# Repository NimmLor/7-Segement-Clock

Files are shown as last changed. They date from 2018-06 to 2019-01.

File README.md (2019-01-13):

# THIS REPO IS NO LONGER UPDATED, VISIT THE THINGIVERSE PROJECT FOR UPDATED FILES

This is a fully 3D printed clock that was designed in Fusion 360. The project is based on [Ivan Miranda's Big Digital Clock](https://ivanmiranda.com/diy-big-digital-clock) and was completely re-designed.

## If you have any questions or issues feel free contact me 

#### *Mini version* of the clock coming soon :)

## Changelog:

## Major Software Update: 24.09.2018
**Make sure to update all your libraries (3 dashes → manage palette → update)**
- **LOTS OF BUG FIXES**
  - Clock does no longer light up every 6 hours even when turned of
  - Fixed a bug when clock mode was selected at 00:00 - 00:59 that it would made it show e.g. 24:15
  - Fixed random reboots
  - Fixed that alarm wouldn't trigger at the correct time
  - Fixed a bug that occured when the API-key of *openweathermap* wasn't set
  - Fixed error spamming in debug console of Node-red
  - Fixed that timer would skip 1 second every minute
  - Fixed bugs that would result in a crash of the clock
  - and much more...
- Removed unnecessary buttons in the UI
- Added a **settings tab** to the UI, the *settings* section in the ui got moved over there
- Clock is now **more precise**
- Timer is now capable of displaying HH:MM and MM:SS format, depending on the remaining time
- **SOURCE CODE OVERHAUL**
  - Functions are now **modular**
  - Added tons of **comments**
  - Made the code **readable**
  - **New** functions
  - Clock/Timer works now more precise (the clock shouldn't be off time more than 2 secs)
  - Functions utilize much less global variables making the code easier to modify
  - Weather algorithm got fixed
  - Fade works more stable now and shouldn't cause a crash anymore
  - Time is now set in **HH:MM:SS** before it was HH:MM
- Clock now request the time on startup and after connection loss
- Custom values now allow to **disable digits**
- Fixed fade-speed levels
- Node-red flows are now much more modular, this allows controlling additional clocks
- **Debug Serial** mode for the clock -> debugging can be disabled -> more stability
- Brightness slider is now logarithmic
- Fixed some typos
- Easy way to control more clock implemented
- Time offset should now be persistent
- Added **Settings** page
- Improved **Alarm** Creation
  - Fixed tons of bugs
  - Added alternative input formats
  - Added input check → the user gets informed if the values aren't correct
  - Adapted the form to the new dashboard plugin update
  - The alarm triggers now at the correct time :D
- and more...

## Hotfix: 14.07.2018

- Fixed a bug in the arduino code that would cause the shutdown of the clock if the weather gets displayed
- Due to an update of the dashboard library some code had to be changed for the timer

## Hotfix: 05.07.2018

- Updated **diffuser_white_28x**, fixed the tiny hole on the bottom

#### All files and photos can be found at: [Github](https://github.com/NimmLor/7-Segement-Clock)

### Tested devices
 - Raspberry Pi 3B
 - Raspberry Pi B+
 - Wemos D1 mini
 - Generic ESP8266 (Led Strip Pin must be changed)

## Features

- Responsive **webinterface**

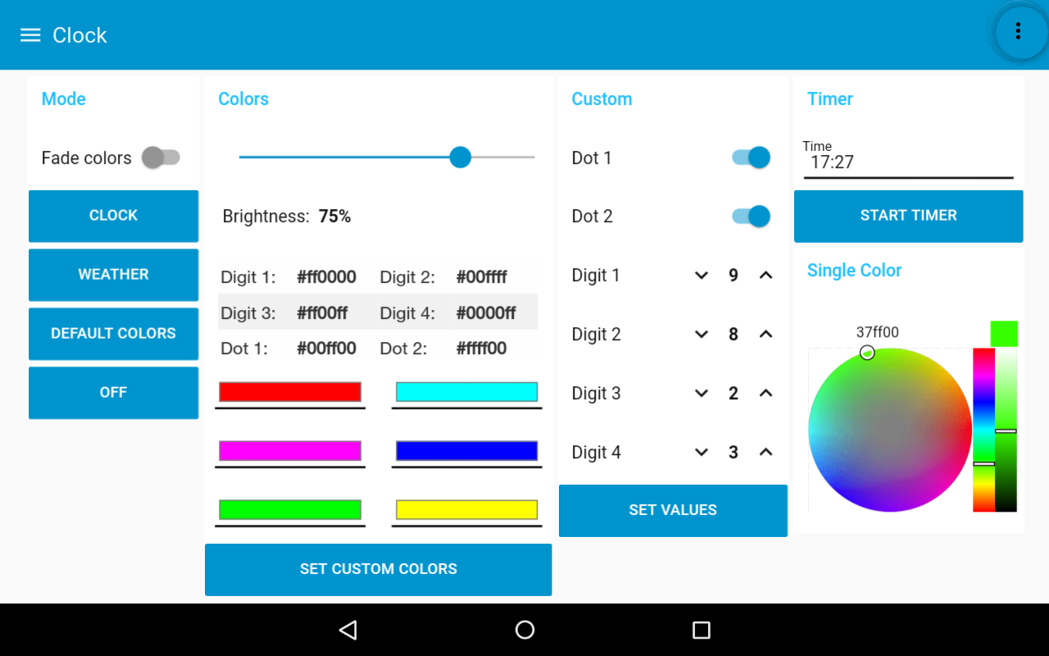
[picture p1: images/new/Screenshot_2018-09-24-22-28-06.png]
Webinterface


- Create **alarms**

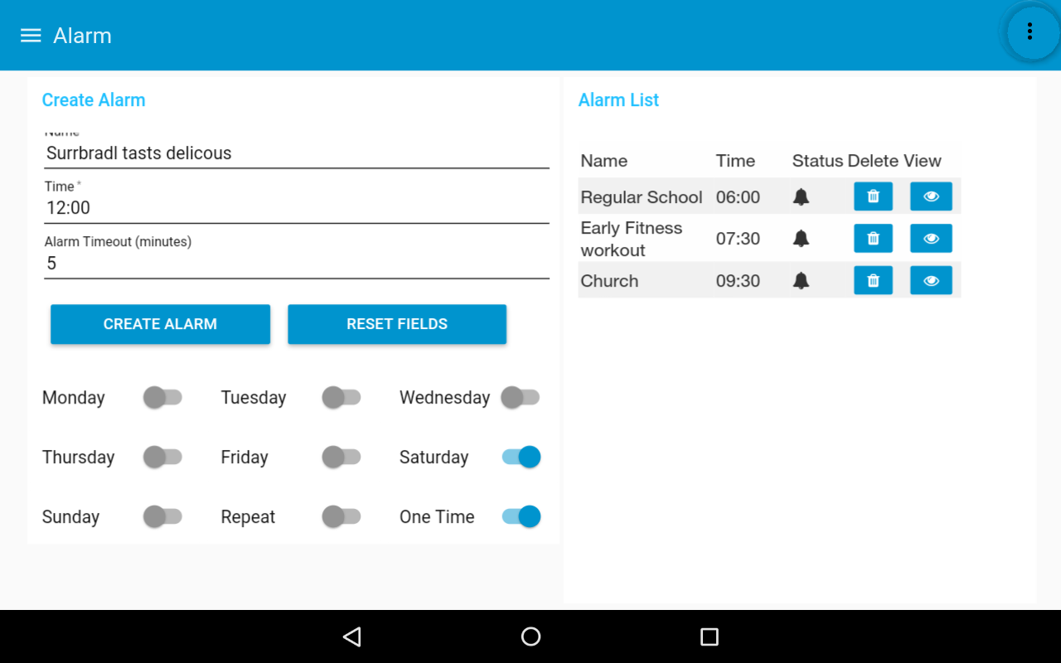
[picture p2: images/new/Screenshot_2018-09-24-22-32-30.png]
Webinterface alarm


- Show current temperature in your region

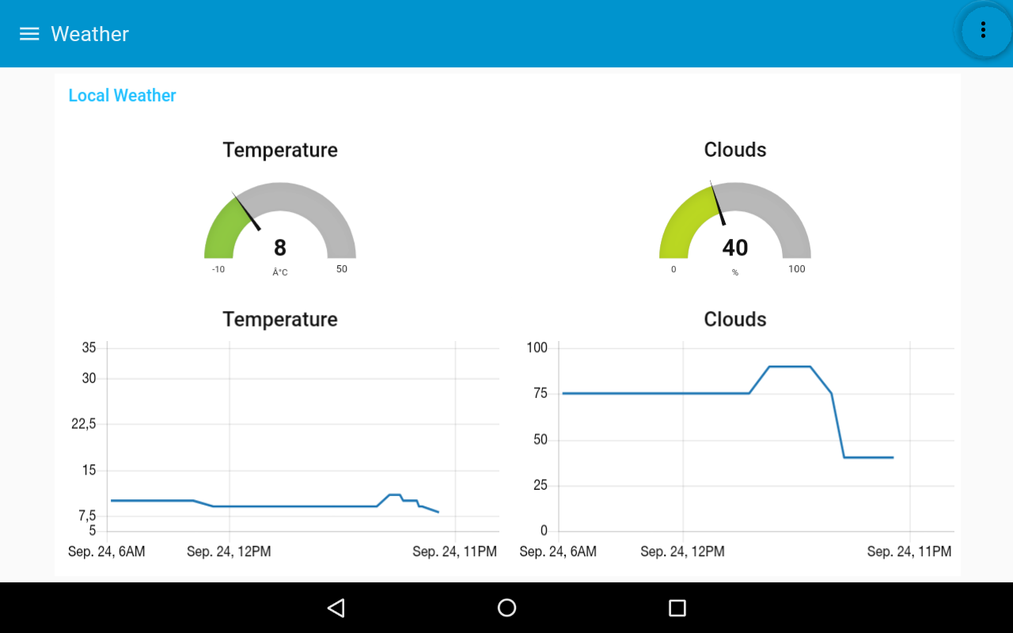
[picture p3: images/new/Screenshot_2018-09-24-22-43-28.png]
Webinterface weather


- Configure settings

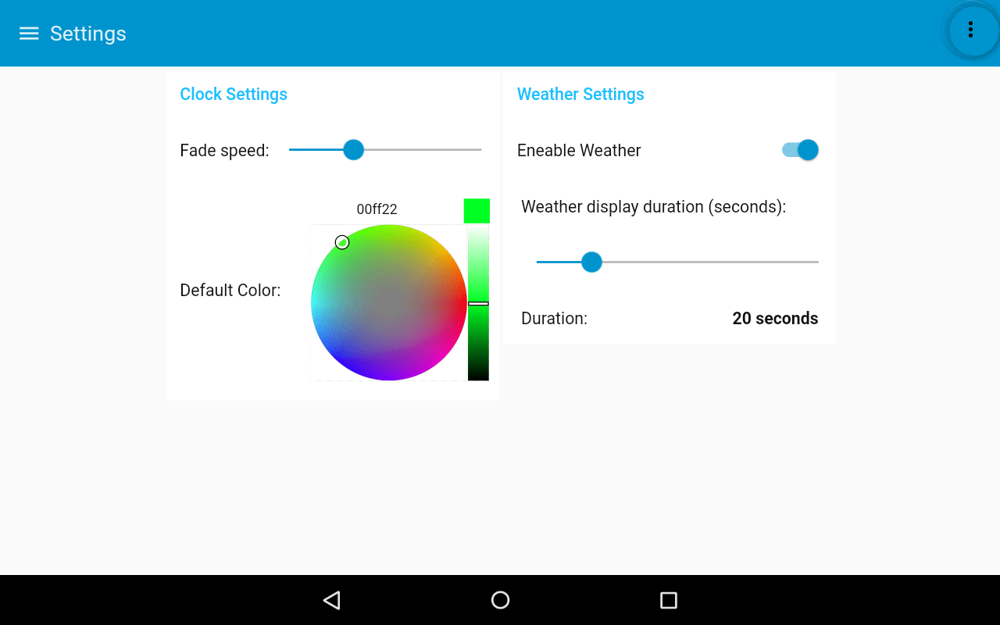
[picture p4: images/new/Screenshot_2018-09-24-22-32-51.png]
Webinterface settings


- Display local time
- Set **individual colors** of each digit
- Custom **scoreboard** mode 
- Control brightness
- Save **custom colors**
- **Fade** colors

# Bill of materials
- 1x [Raspberry Pi](https://www.amazon.de/Raspberry-Pi-Model-ARM-Cortex-A53-Bluetooth/dp/B01CD5VC92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) or any linux machine
- 1x [Wemos d1 mini](http://s.click.aliexpress.com/e/MzRFIIE)
- 1x [1m of WS2812 LED strip with 60 LED's](http://s.click.aliexpress.com/e/EiMfaA2)
- 1x [Power supply 5V, 4A](https://de.aliexpress.com/item/-/32729613841.html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)
- 16x [M3 * 10-16mm](http://s.click.aliexpress.com/e/zRNRrrz)
- 16x [M3 Nuts](http://s.click.aliexpress.com/e/a2JeIEQ)
- 1x [Power jack adapter](http://s.click.aliexpress.com/e/Jyvj2vb)
- 2m [Wire](http://s.click.aliexpress.com/e/rzvNFUb)
- 4x [Dupont connectors](http://s.click.aliexpress.com/e/6UvBeYZ)
- ##### Estimated total price: 25€ not including the raspberry pi

## Tools

- Soldering iron
- 3D Printer
- Pliers
- Hot glue gun

# How to build it

## 1. 3D-Print

#### Print Settings

##### Attention: diffuser and dot_diffuser must be printed at 100% infill!

| Part | frame  | dot_frame | back_cover | dot_back_cover | diffuser | dot_diffuser |
| :----- | --- | --- | --- | --- | --- | --- |
| Speed  | 45mm/s | 45mm/s | 45mm/s | 45mm/s | 25mm/s | 25mm/s |
| Infill | 15% | 15% | 15% | 15% | **100%** | **100%** |
| Layer  | 0.2mm  | 0.2mm | 0.2mm | 0.2mm | 0.2mm | 0.2mm |
| Color  | Black  | Black | Black | Black | White | White |
| Amount | 4 | 1 | 4 | 1 | 28 | 2 |

## 2. Soldering of the LED-Strips

First the LED strips have to be cut into pieces of 2 LEDs each, then the ends have to be bent until the solder pads are exposed. It is recommended to tape the strips onto a soldering mat or a table and solder the wires afterwards. 

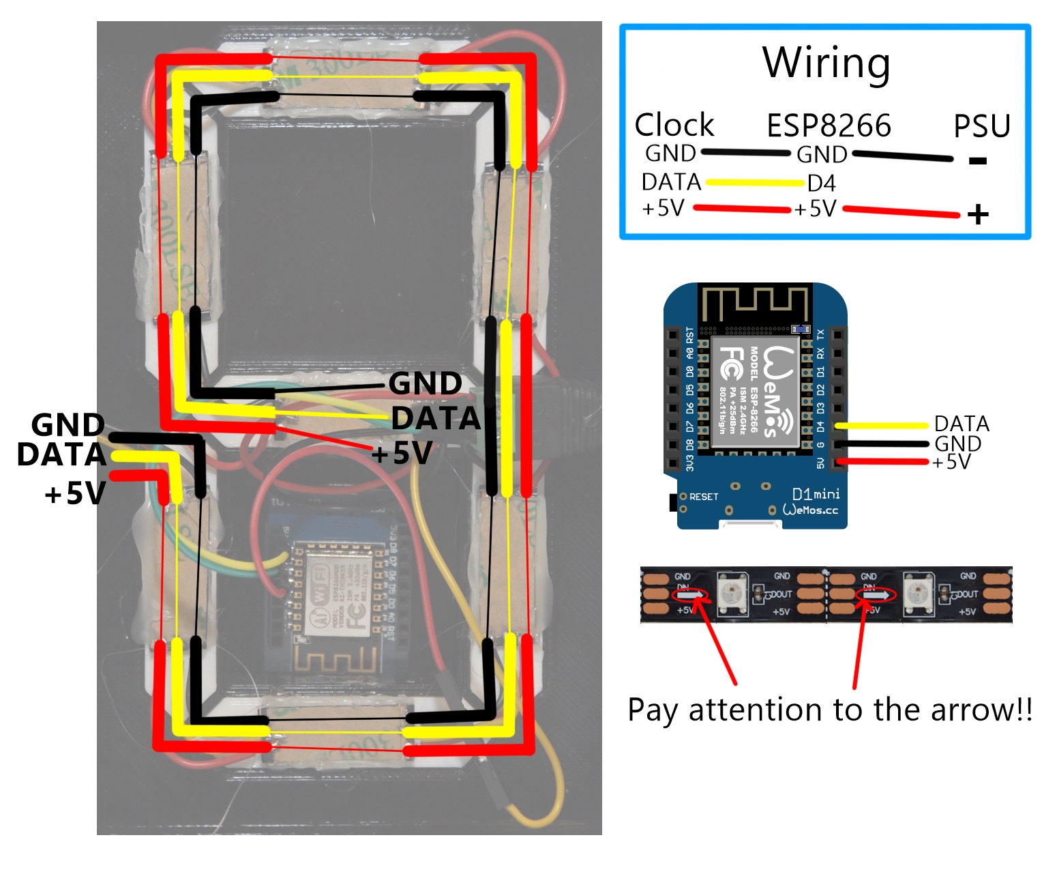
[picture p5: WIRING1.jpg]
Wiring


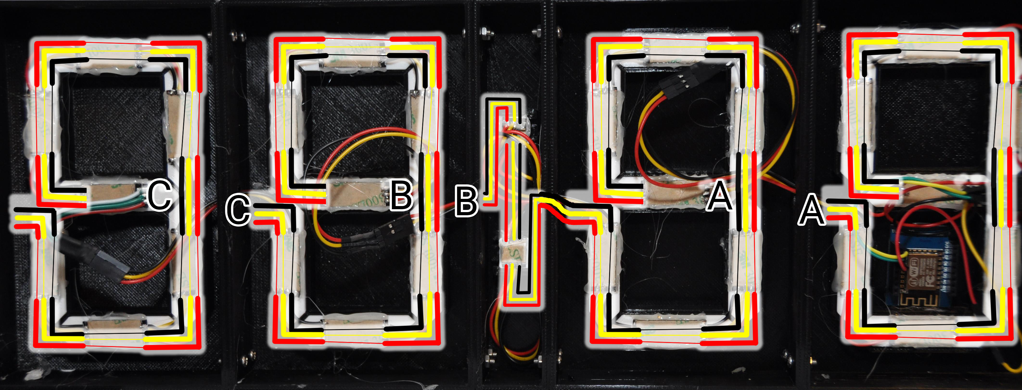
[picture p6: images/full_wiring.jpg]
full wiring


Be careful when wiring the dots, only **one** LED was used for these pieces. 

## 3. Testing the LEDs

Upload the *clock_mqtt.ino* sketch onto the ESP8266, if the leds don't show *0:0:0:1* after one minute, then you made a mistake or have loose wires somewhere.

## 4. Assembling the frame

Push in all 30 diffusers, use the 16 M3 screws and nuts to assemble the frame. This step should be self explainatory.

## 5. Glue in the LEDs 

A hot glue gun needs to be used to glue on all LED strips. The start of the LED strip and the ESP8266 must be located on the left when looking at the clock from the front. Afterwards also glue on the microcontroller and the power jack once everything works the way it should. Finally attach the back covers.

# Setup

## 1. Raspberry Pi
- You could also install this on any linux machine

In case help with Raspberry Pi is needed, click [here](https://www.imore.com/how-get-started-using-raspberry-pi).

#### 1. Install Node-RED

`bash <(curl -sL https://raw.githubusercontent.com/node-red/raspbian-deb-package/master/resources/update-nodejs-and-nodered)`

#### 2. Install npm - this might be already installed

`sudo apt-get install nodejs npm -y`

#### 3. Install dashboard, openweathermap and mysql

`cd $HOME/.node-red`
`npm install node-red-dashboard`

- if you get an error try: `npm install  --unsafe-perm node-red-dashboard`

`npm install node-red-node-openweathermap`
`npm install node-red-node-mysql`

#### 4. Install mosquitto

`sudo apt-get install mosquitto -y`
(optional) [Setup mosquitto authentication](http://www.steves-internet-guide.com/mqtt-username-password-example/)

#### 5. Install mysql

`sudo apt-get install mysql-server -y`

   - Just hit **OK** or **RETURN** during installation

#### 6. Setup a static ip for your raspberry pi

   - (recommended) Setup a static ip on your router
   - [or on your Raspberry Pi](http://www.circuitbasics.com/how-to-set-up-a-static-ip-on-the-raspberry-pi/)

#### 7. Create Database clock and account
You will have to create a database named **clock** to be able to save alarms. Just type into your shell:

`mysql -uroot`

`create database clock;`

`CREATE USER 'admin'@'localhost' IDENTIFIED BY 'raspberry';`

`GRANT ALL PRIVILEGES ON clock.* TO 'admin'@'localhost';`

`FLUSH PRIVILEGES;`

`quit`

## 2. Node-RED

#### 1. Start node-red
- `sudo node-red-start`

#### 2. Open node-red
- <http://yourRaspberryIP:1880>

#### 3. Import the flows
- Click on the 3 dashes in the top right corner → import → clipboard
- Enter the code snippet from **all_flows_v2.txt** and click **import**

#### 4. Head to the Thingiverse_Settings flow
#### 5. Edit the mqtt node
   - Set topic to **clock**
   - Edit **broker** and enter **localhost** in the IP field
     - If you had set up authentication before, the credentials must be entered in the **Security** tab 

#### 6. Edit the mysql node
   - Edit the mysql connection
     - IP: **127.0.0.1**
     - Username: **admin**
     - Password: **raspberry**
     - Database: **clock**

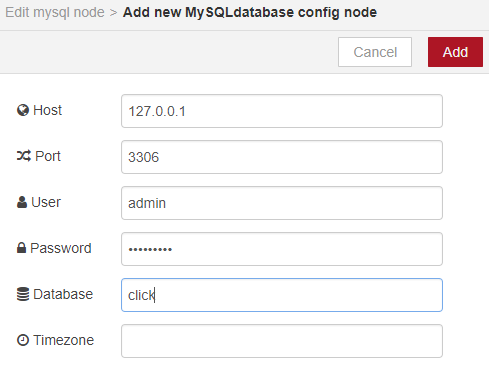
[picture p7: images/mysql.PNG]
mysql node settings


#### 7. Click on the latch of the node *CREATE TABLE*
#### 8. Double click on the node *TIME OFFSET*
   - Enter the offset of the time, Germany and Austria would be = 1

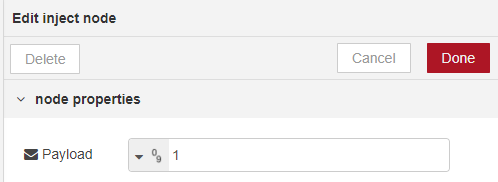
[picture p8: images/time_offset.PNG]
Time offset


#### 9.  Get local temperatures from *OpenWeatherMap*

- If temperature output is not needed, just delete the flow *Thingiverse_weather* and the weather section in the *Thingiverse_clock* flow.
- Head over to [OpenWeatherMap](https://home.openweathermap.org/users/sign_up) and create an account
- Click on API-Keys and copy the value

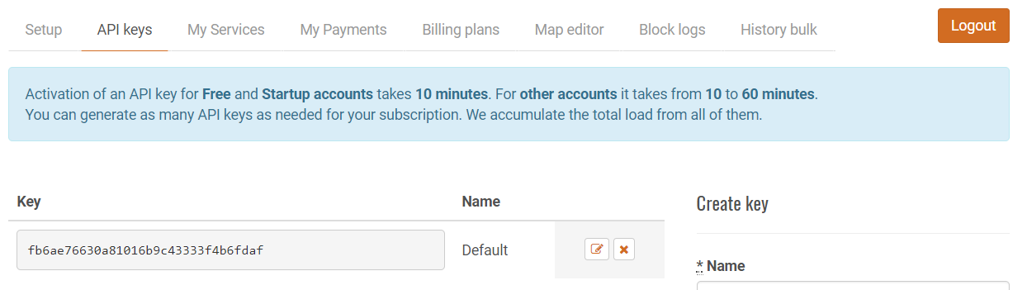
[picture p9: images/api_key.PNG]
API-Key


- Afterwards copy that key into the *openweathermap* node in the *Thingiverse_weather* flow.
- Either pick geo-coordinates or city to get the temperatures.

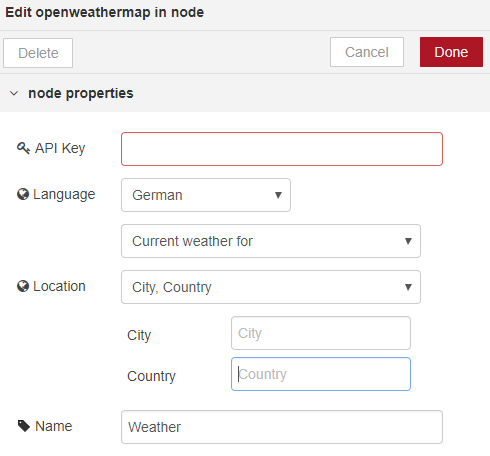
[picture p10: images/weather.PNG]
owm node


#### 10.Connect to the webinterface

- Hit **DEPLOY**
- Now you can connect to the UI via: http://yourRaspberryIP:1880/ui

#### 11. Customize the webinterface

- The webinterface is designed to fit the whole screen of the *Fire HD 8* Tablet, to fit your phone you have to change the dimensions of the elements. 
- You can change the position by dragging the elements in the dashboard list.

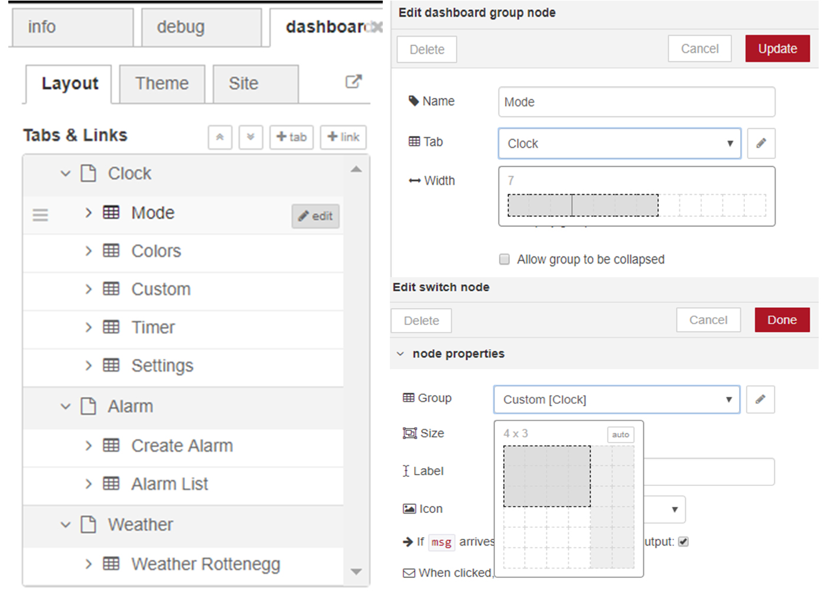
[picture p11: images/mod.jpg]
Dashboard element list


#### 12. Change theme of the webinterface
- You can either choose one of the two default themes or set your own colors.

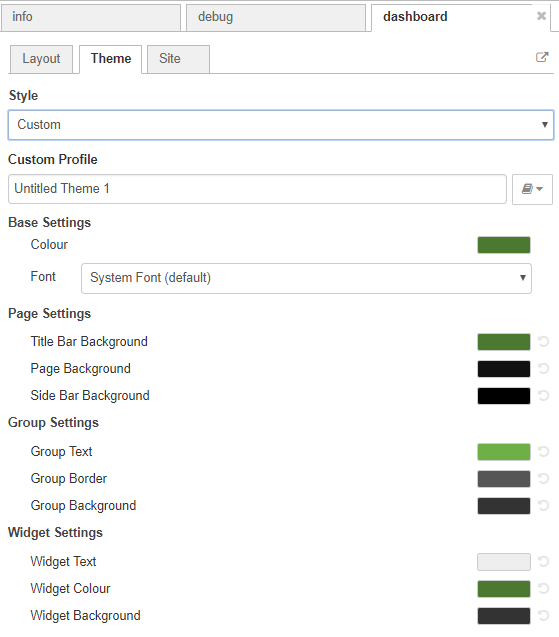
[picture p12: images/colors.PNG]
customize


## 3. ESP8266

#### 1. Install Arduino IDE
   - https://www.arduino.cc/en/main/software

#### 2. Add ESP8266 boards to the Arduino IDE

      1. Click on preferences
      2. Enter under *Additional Board Manager URLs*:
      http://arduino.esp8266.com/stable/package_esp8266com_index.json
      3. Now head to tools → Board → Boards-Manager
      - Search for **esp8266** and install the package
      4. Select **WeMos D1 R2 & mini** from the boards list

#### 3. Install libraries

      1. Click on sketch → include libary → manage labraries
      2. Install *PubSubClient*
      3. Install *Adafruit Neopixel*

#### 4. Now open the file *clock_mqtt_v2.ino*
#### 5. Edit the code
      1. Set your WiFi SSID and WiFi password
      2. Set **mqtt_server** to your Raspberry Pi's IP-Address
      3. If you had set up authentication before, change **mqtt_auth** to 1 and enter your credentials below, otherwise set it to 0

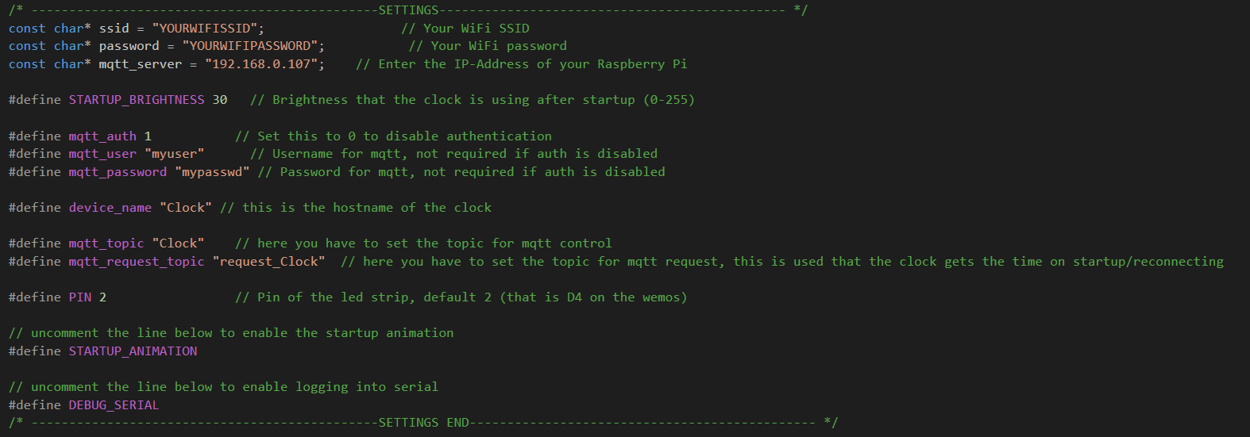
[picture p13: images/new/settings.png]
arduino code


#### 6. Choose the correct COM-Port of the ESP8266 under tools → Port
#### 7. Hit **Upload**

# Congratulations you made it, have fun! ☺

## 4. My setup 

The table i'm using is an **Amazon Fire HD 8** with an app called **One Page Web Browser**, this app can be found [here](https://play.google.com/store/apps/details?id=cz.mivazlin.onepagewebbrowser).

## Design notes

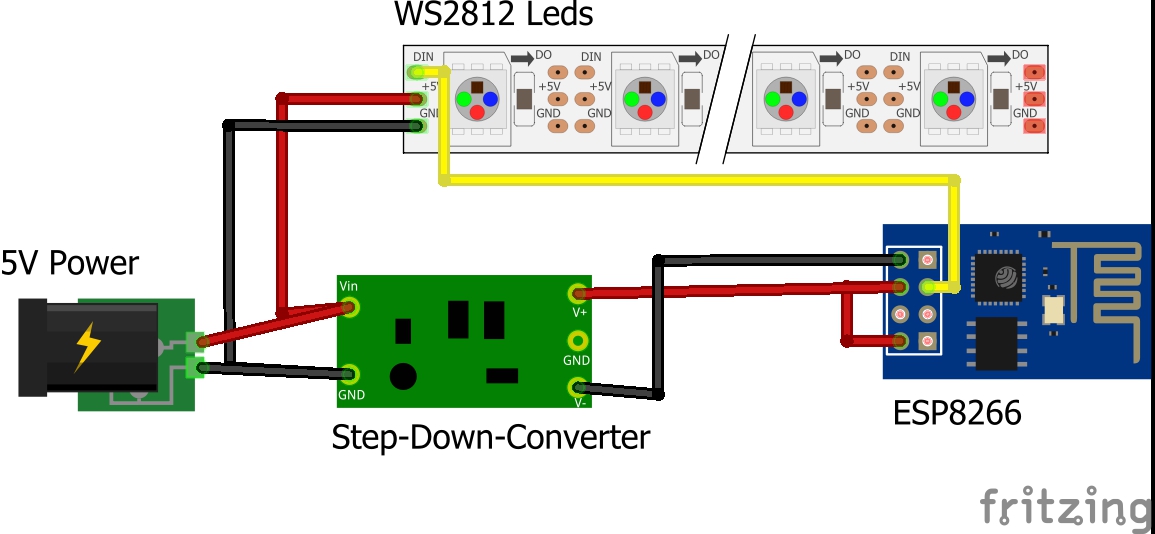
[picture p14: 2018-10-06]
miniclock/gallary/schematic.jpg

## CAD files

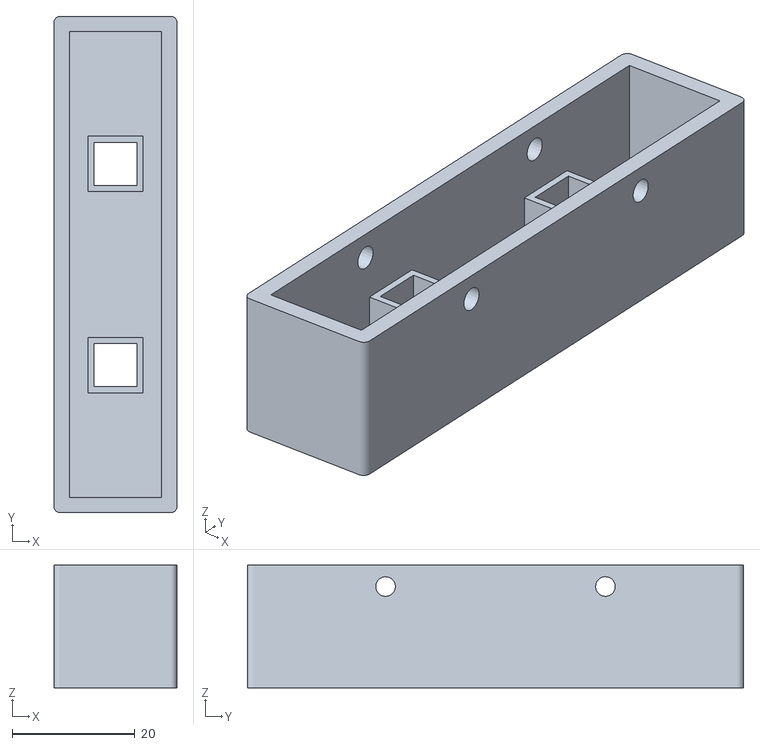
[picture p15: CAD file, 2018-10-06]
miniclock/dot_frame_40Infill_Black_1x.stl
20.0 x 80.7 x 20.0

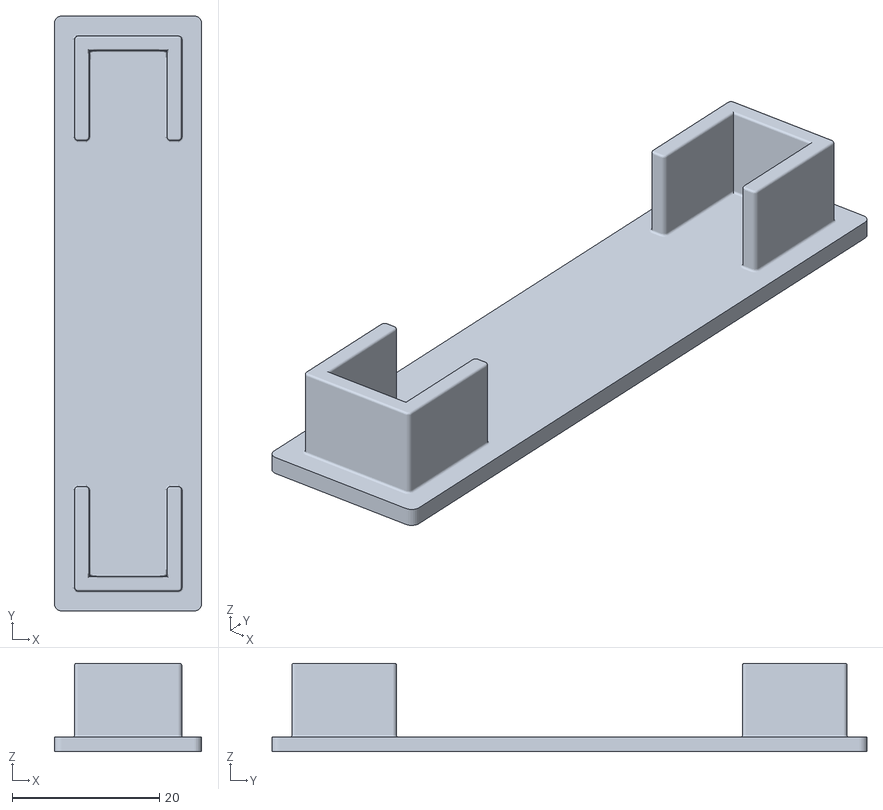
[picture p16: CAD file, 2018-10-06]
miniclock/dot_back_cover_40Infill_Black_1x.stl
20.0 x 80.7 x 12.0

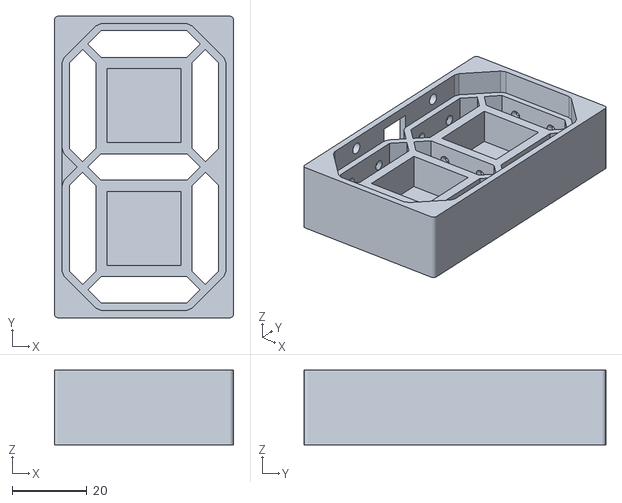
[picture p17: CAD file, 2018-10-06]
miniclock/frame_1_40Infill_Black_1x.stl
47.9 x 80.7 x 20.0

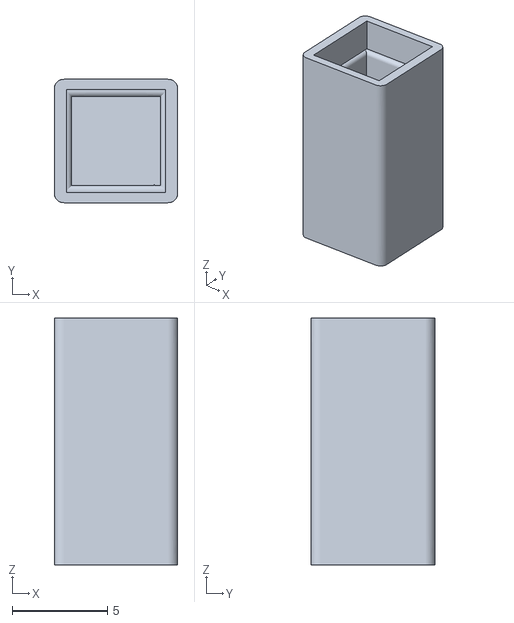
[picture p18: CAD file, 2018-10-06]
miniclock/dot_diffuser_100Infill_White_2x.stl
6.50 x 6.50 x 13.0

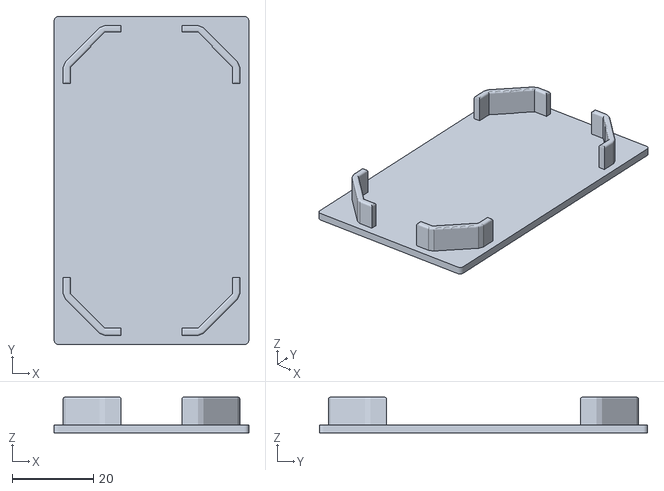
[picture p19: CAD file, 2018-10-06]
miniclock/back_cover_40Infill_Black.stl
47.9 x 80.7 x 8.80

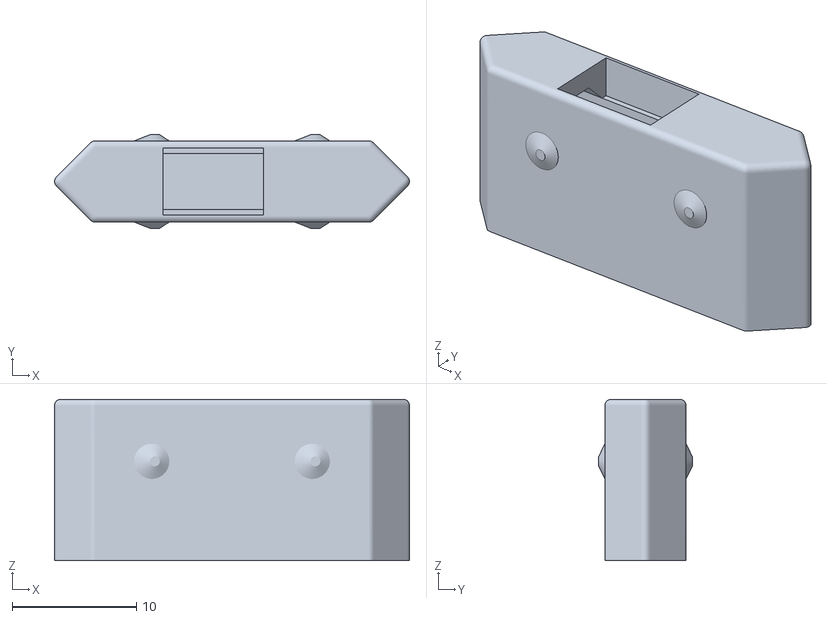
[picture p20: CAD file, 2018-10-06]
miniclock/diffuser_100Infill_White_28x.stl
28.6 x 7.53 x 13.0

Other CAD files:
miniclock/frame_2_40Infill_Black_1x.stl
miniclock/frame_3_40Infill_Black_1x.stl
miniclock/frame_4_40Infill_Black_1x.stl
miniclock/clock_mini v28.f3d

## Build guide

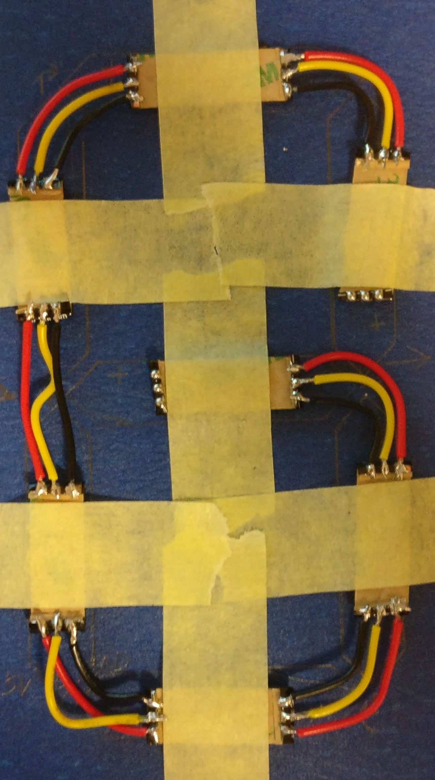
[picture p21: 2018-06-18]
images/soldering.jpg

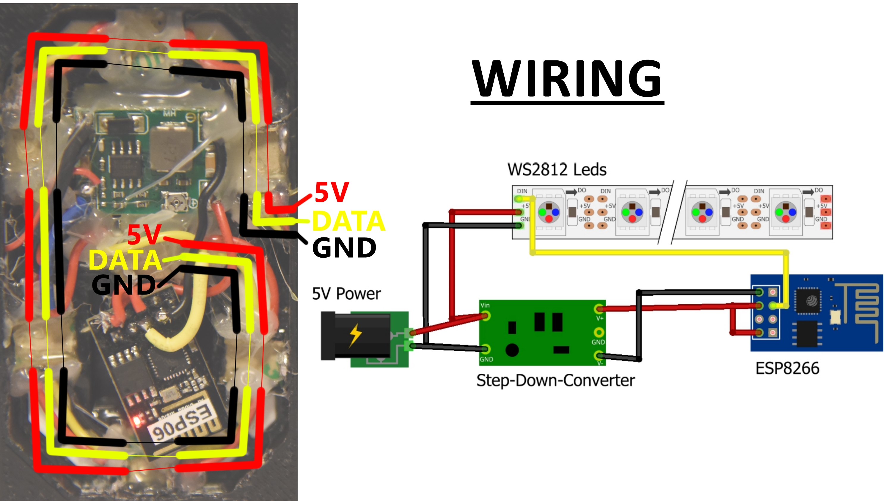
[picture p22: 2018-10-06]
miniclock/gallary/wiring1.jpg

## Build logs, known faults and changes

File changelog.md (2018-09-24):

# Known issues:

- Entering a time into the timer field causes the time to be displayed in HH:MM format
- Leaving the clock on the maximum fade speed for a longer duration might cause a kernel panic on certain esp8266 boards, possible solution: adding a 100uF Capacitor between VCC and GND

## Changelog:

## Major Update: 24.09.2018

- **LOTS OF BUG FIXES**
  - Clock does no longer light up every 6 hours even when turned of
  - Fixed a bug when clock mode was selected at 00:00 - 00:59 that it would made it show e.g. 24:15
  - Fixed random reboots
  - Fixed that alarm wouldn't trigger at the correct time
  - Fixed a bug that occured when the API-key of *openweathermap* wasn't set
  - Fixed error spamming in debug console of Node-red
  - Fixed that timer would skip 1 second every minute
  - Fixed bugs that would result in a crash of the clock
  - and much more...
- Removed unnecessary buttons in the UI
- Added a **settings tab** to the UI, the *settings* section in the ui got moved over there
- Clock is now **more precise**
- Timer is now capable of displaying HH:MM and MM:SS format, depending on the remaining time
- **SOURCE CODE OVERHAUL**
  - Functions are now **modular**
  - Added tons of **comments**
  - Made the code **readable**
  - **New** functions
  - Clock/Timer works now more precise (the clock shouldn't be off time more than 2 secs)
  - Functions utilize much less global variables making the code easier to modify
  - Weather algorithm got fixed
  - Fade works more stable now and shouldn't cause a crash anymore
  - Time is now set in **HH:MM:SS** before it was HH:MM
- Clock now request the time on startup and after connection loss
- Custom values now allow to **disable digits**
- Fixed fade-speed levels
- Node-red flows are now much more modular, this allows controlling additional clocks
- **Debug Serial** mode for the clock -> debugging can be disabled -> more stability
- Brightness slider is now logarithmic
- Fixed some typos
- Easy way to control more clock implemented
- Time offset should now be persistent
- Improved **Alarm** Creation
  - Fixed tons of bugs
  - Added alternative input formats
  - Added input check → the user gets informed if the values aren't correct
  - Adapted the form to the new dashboard plugin update
  - The alarm triggers now at the correct time :D
- and more...

## Hotfix: 14.07.2018

- Fixed a bug in the arduino code that would cause the shutdown of the clock if the weather gets displayed
- Due to an update of the dashboard library some code had to be changed for the timer

## Hotfix: 05.07.2018

- Updated **diffuser_white_28x**, fixed the tiny hole on the bottom

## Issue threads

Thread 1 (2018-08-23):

Attempting MQTT connection...failed

DynaMight1124, 2018-08-23:
Hi

I've printed and made the clock, just struggling with the software side. The clock itself is working correctly as I edited the original code from Ivan Miranda's Big Digital Clock to work with the 2 LED's per diffuser and that works great.

I've got a raspberry pi, installed all the software which seems to be fine but just cant get the clock to connect to the pi. The serial monitor on Arduino just states: Attempting MQTT connection...failed, rc=-2 try again in 5 seconds

Quick google and seems to be a fairly common issue with MQTT with some network setups, I'm just not sure how to fix it, but seems to be related to Arduino code.

Any idea?

NimmLor, 2018-09-24:
Hi, sorry for that late response, today i will release a new and improved version of the code with a lot of improvements and bug fixes. You might want to try that.

DynaMight1124, 2018-10-02:
Hi

I tried the new version, everything else worked fine (the wrong flow is on Github btw, I got the correct one from Thingiverse) but I still get the same error message. My network setup is pretty standard, just a router with wireless, the Pi is connected by cable to a switch.  I've tried relaxing some firewall settings just incase.

I've tried a Pi3 and a Pi2, wired and wireless. I get the same error message as before. Same error if the Pi is plugged in or not so nothing is getting through to the Pi at all. Everything on the Pi seems to be working.

Any ideas?

NimmLor, 2018-10-02:
have you installed the mqtt broker on the pi?
ensure that the ip in the arduino code matches your Pi's ip
have you set up a mqtt password, if you have one you must set it in the arduino code
try starting mosquitto broker manually on the raspberry: `mosquitto -d`

// Testing the mqtt broker
install the mqtt client: `sudo apt-get install mosquitto-clients`
subscribing to the mqtt topic: `mosquitto_sub -d -t clock`
Now if you interact on the UI u should see some messages
If you get an error you should try reinstalling the mqtt broker

Closed 2019-01-21.

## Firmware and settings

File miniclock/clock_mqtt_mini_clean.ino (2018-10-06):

#include <Adafruit_NeoPixel.h>
#include <ESP8266WiFi.h>
#include <PubSubClient.h>


/* ----------------------------------------------SETTINGS---------------------------------------------- */
const char* ssid = "YOURWIFINAME";                  // Your WiFi SSID
const char* password = "YOURPASSWORD";           // Your WiFi password
const char* mqtt_server = "192.168.0.107";    // Enter the IP-Address of your Raspberry Pi


#define mqtt_auth 0           // Set this to 0 to disable authentication
#define mqtt_user "YOURUSERNAME"      // Username for mqtt, not required if auth is disabled
#define mqtt_password "YOURPASSWORD" // Password for mqtt, not required if auth is disabled

#define mqtt_topic "miniclock"    // here you have to set the topic for mqtt

#define PIN 2                 // Pin of the led strip, default 2 (that is D4 on the wemos)
/* ----------------------------------------------SETTINGS END---------------------------------------------- */


/* ----------------------------------------------GLOBALS---------------------------------------------- */
int mqttdata = 0;
WiFiClient espClient;
PubSubClient client(espClient);
int hours = 0;
int mins = 0;

// Timer stuff
int T_hours = 0;
int T_mins = 0;
int T_secs = 0;
unsigned long timermillis = 0;
unsigned long weathermillis;
unsigned long alarmmillis;

int weathersecs = 0;

int alarmstate = 0;
int alarmcounter = 0;

int pt1 = 0;
int pt2 = 0;

// State of the dots
int dot1 = 0;
int dot2 = 0;

unsigned long timemillis;

int newData = 0;
const byte numChars = 50;
char receivedChars[numChars]; // an array to store the received data

// Numbers for the digits
int d1 = 99;
int d2 = 99;
int d3 = 99;
int d4 = 99;

// Color of the digits
int cd[] = { 255, 255, 255, 255, 255, 255, 255, 255, 255, 255, 255, 255 };

// Color of the alarm digits
int fadespeed = 0;
int fadeamount = 0;
int ad = 0;
int ar = 255;
int ag = 255;
int ab = 255;

// Colors of the dots
int cdo[] = { 255, 255, 255, 255, 255, 255 };

int wr = 255;
int wg = 255;
int wb = 255;

char type = '0';  // current mode
char mymode2 = '0';
char old_type = '0';  // current mode

char vals[14][6] = { "", "", "", "", "", "", "", "", "", "", "", "", "", "" };
/* ----------------------------------------------GLOBALS END---------------------------------------------- */


/* ----------------------------------------------LED STRIP CONFIG---------------------------------------------- */
#define NUMPIXELS      30
//offsets
#define Digit1 0
#define Digit2 7
#define Digit3 16
#define Digit4 23

Adafruit_NeoPixel pixels = Adafruit_NeoPixel(NUMPIXELS, PIN, NEO_GRB + NEO_KHZ800);
/* ----------------------------------------------LED STRIP CONFIG END---------------------------------------------- */


/* ----------------------------------------------FUNCTIONS START---------------------------------------------- */

/*
 * Function: serialNew
 * Used to process new data
 * Called when a new message arrives
 * Parameters: none
 */
void serialNew() {
	displayData();
	GetMode();
	CallMode();
	newData = false;
	mqttdata = 0;
}

/*
 * Function: displayData
 * Prints the message into serial console for debugging
 * Called when a new message arrives
 * Parameters: none
 */
void displayData()
{
	if (newData == true) {
		Serial.print("This just in ... ");
		Serial.println(receivedChars);
	}
}

/*
 * Function: GetMode
 * Extracts the type from the first character of the message
 * Called when a new message arrives
 * Parameters: none
 */
void GetMode()
{
	old_type = type;
	if (old_type == '0')pixels.setBrightness(40);
	type = receivedChars[0];
}

/*
 * Function: CallMode
 * Function calls the corresponding function to the type character
 * Called when a new message arrives
 * Parameters: none
 */
void CallMode()
{
	char mymode = type;
	if (mymode == 's')SetTime();      // s;2;2;5;8
	if (mymode == 'd')SetDots();      // d;1;0
	if (mymode == 'e')SetDotColors(); // e;255;0;0;0;255;0
	if (mymode == 'h')Set1DotColor(); // h;1;255;0;0
	if (mymode == 'i')Set1Dot();      // i;1
	if (mymode == 'f')Set1Color();    // f;1;8;255;34
	if (mymode == 'g')SetColors();    // g;255;10;3;100;255;200;255;10;3;100;255;200
	if (mymode == 'c')ModeClock();    // ignore
	if (mymode == 'z')CustomValues(); // z;0;2;0;4
	if (mymode == 'a')SetMode();      // a;c
	if (mymode == 't')SetTimerDyn();  // t;01;15;30
	if (mymode == 'b')SetBrightness();//b;80
	if (mymode == '!')Alarm();        // !
	if (mymode == '0')Off();          // a;0
	if (mymode == 'w')Weather();      // w;1;9;+;1;5
	if (mymode == '*') {
		mymode2 = '*';
		SetFadeSpeed();
	}
	if (mymode == '#')mymode2 = '0';
	if (mymode == '*' || mymode == '#' || mymode == '0' || mymode == '!')ResetAlarmLeds();
	pixels.show();
}


/*
 * Function: ResetAlarmLeds
 * Resets alarm status to initial values
 * Called when alarm ends
 * Parameters: none
 */
void ResetAlarmLeds()
{
	ad = 0;
	ar = 255;
	ag = 255;
	ab = 255;
}

/*
 * Function: Weather
 * Extracts temperature readings and display duration from the message,
 * afterwards it draws the temperature symbol(°C) and the temperature
 * Called when a type is 'w'
 * Parameters: none
 */
void Weather()
{
	int t1 = receivedChars[2] - '0';
	int t2 = receivedChars[4] - '0';
	pt1 = t1;
	pt2 = t2;
	char vz = receivedChars[6];
	weathersecs = (receivedChars[8] - '0') * 10 + receivedChars[10] - '0';
	int temp = t1 * 10 + t2;
	if (vz == '-')temp = temp * (-1);

	for (int i = 0; i < NUMPIXELS; i++)pixels.setPixelColor(i, pixels.Color(0, 0, 0));

	//WeatherSymbols
	pixels.setPixelColor(Digit3 + 0, pixels.Color(61, 225, 255));
	pixels.setPixelColor(Digit3 + 1, pixels.Color(61, 225, 255));
	pixels.setPixelColor(Digit3 + 2, pixels.Color(61, 225, 255));
	pixels.setPixelColor(Digit3 + 3, pixels.Color(61, 225, 255));

	pixels.setPixelColor(Digit4 + 2, pixels.Color(61, 225, 255));
	pixels.setPixelColor(Digit4 + 3, pixels.Color(61, 225, 255));
	pixels.setPixelColor(Digit4 + 4, pixels.Color(61, 225, 255));
	pixels.setPixelColor(Digit4 + 5, pixels.Color(61, 225, 255));

	weathermillis = millis();
	GetWeatherColor(temp);
	if (vz == '-' && t1 == '0') {
		pixels.setPixelColor(Digit3 + 0, pixels.Color(61, 225, 255));
		pixels.setPixelColor(Digit3 + 1, pixels.Color(61, 225, 255));
	}
	if (t1 != 0)
	{
		if (mymode2 == '*')DrawDigit(Digit1, ar, ag, ab, t1);
		else DrawDigit(Digit1, wr, wg, wb, t1);
	}
	if (mymode2 == '*')DrawDigit(Digit2, ar, ag, ab, t2);
	else DrawDigit(Digit2, ar, ag, ab, t2);
	pixels.setPixelColor(Digit3 - 2, pixels.Color(0, 0, 0));
	pixels.setPixelColor(Digit3 - 1, pixels.Color(0, 0, 0));
	pixels.show();
	Serial.printf("Showing the weather for %d seconds\n", weathersecs);


	if (t1 != 0)DrawDigit(Digit1, wr, wg, wb, t1);
	DrawDigit(Digit2, wr, wg, wb, t2);
	pixels.setPixelColor(Digit3 - 2, pixels.Color(0, 0, 0));
	pixels.setPixelColor(Digit3 - 1, pixels.Color(0, 0, 0));
	pixels.show();
	Serial.printf("Showing the weather for %d seconds\n", weathersecs);
}

/*
 * Function: GetWeatherColor
 * Used to get temperature color, high temperature = more yellow, low temperature = more blue
 * Called by function Weather
 * Parameters: temperature in °C
 */
void GetWeatherColor(int temp)
{
	int R = 255; int G = 255; int B = 255;
	String hex = "";
	if (temp < -40) {
		R = 0;
		G = 197;
		B = 229;
	}
	else if (temp < -30) {
		R = 28;
		G = 203;
		B = 204;
	}
	else if (temp < -20) {
		R = 56;
		G = 209;
		B = 180;
	}
	else if (temp < -10) {
		R = 84;
		G = 216;
		B = 156;
	}
	else if (temp < 0) {
		R = 112;
		G = 222;
		B = 131;
	}
	else if (temp < 4) {
		R = 140;
		G = 229;
		B = 107;
	}
	else if (temp < 8) {
		R = 168;
		G = 235;
		B = 83;
	}
	else if (temp < 14) {
		R = 196;
		G = 242;
		B = 58;
	}
	else if (temp < 18) {
		R = 224;
		G = 248;
		B = 34;
	}
	else if (temp < 22) {
		R = 253, G = 244, B = 10;
	}
	else if (temp < 26) {
		R = 253, G = 233, B = 10;
	}
	else if (temp < 30) {
		R = 254, G = 142, B = 10;
	}
	else if (temp < 34) {
		R = 254, G = 105, B = 10;
	}
	else if (temp > 40) {
		R = 255, G = 68, B = 10;
	}
	wr = R; wg = G; wb = B;
}

/*
 * Function: Off
 * Turns every pixel off and sets brightness to 0
 * Called when mode is '0'
 * Parameters: none
 */
void Off()
{
	Serial.println("Clock is turning off");
	for (int i = 0; i < NUMPIXELS; i++)
	{
		pixels.setPixelColor(i, pixels.Color(0, 0, 0));
	}
	pixels.setBrightness(0);
	pixels.show();
}

/*
 * Function: Set1Dot
 * Used to set the color of the dot
 * Called when a new message arrives
 * Parameters: none
 */
void Set1Dot()
{
	char temp = receivedChars[2];
	//Serial.print(temp);
	if (temp == '0') {
		pixels.setPixelColor(Digit3 - 1, pixels.Color(0, 0, 0));
		dot1 = 0;
	}
	if (temp == '1') {
		pixels.setPixelColor(Digit3 - 1, pixels.Color(cdo[3], cdo[4], cdo[5]));
		dot1 = 1;
	}
	if (temp == '2') {
		pixels.setPixelColor(Digit3 - 2, pixels.Color(0, 0, 0));
		dot2 = 0;
	}
	if (temp == '3') {
		pixels.setPixelColor(Digit3 - 2, pixels.Color(cdo[3], cdo[4], cdo[5]));
		dot2 = 1;
	}
	DrawDots();
	pixels.show();
	type = old_type;
}


/*
 * Function: SetTimerDyn
 * Used to read time of the message and start the timer
 * Called when mode is "t"
 * Parameters: none
 */
void SetTimerDyn()  //t;01;22;03
{
	int index = 2; int index2 = 0;
	int temp_h = 0; int temp_m = 0; int temp_s = 0;
	temp_h = receivedChars[2] - '0';
	temp_h *= 10;
	temp_h += receivedChars[3] - '0';

	temp_m = receivedChars[5] - '0';
	temp_m *= 10;
	temp_m += receivedChars[6] - '0';

	temp_s = receivedChars[8] - '0';
	temp_s *= 10;
	temp_s += receivedChars[9] - '0';

	T_hours = temp_h;
	T_mins = temp_m;
	T_secs = temp_s;
	Serial.printf("Timer Started: %d:%d:%d\n", T_hours, T_mins, T_secs);
	DrawTimer();
	timermillis = millis();
	type = 't';
	pixels.show();
}


/*
 * Function: SetMode
 * Used to set the mode manually and to print the mode into serial
 * Called when mode is "a"
 * Parameters: none
 */
void SetMode()
{
	type = receivedChars[2];
	Serial.printf("Mode updated: %c", type);
	if (type == '0')Off();
	if (type == 'c') {
		if (mymode2 != '*')DrawTime();
		if (mymode2 != '*')DrawDots();
	}
}

/*
 * Function: SetFadeSpeed
 * Used to determine the fade amount and the fade delay
 * Called when mode is "*"
 * Parameters: none
 * Note: untilize a switch statement instead of 10x if()
 */
void SetFadeSpeed()
{
	//*;5
	int value = receivedChars[2] - '0';
	if (value == 0) {
		fadeamount = 1;
		fadespeed = 1000;
	}
	if (value == 1) {
		fadeamount = 1;
		fadespeed = 500;
	}
	if (value == 2) {
		fadeamount = 1;
		fadespeed = 250;
	}
	if (value == 3) {
		fadeamount = 1;
		fadespeed = 100;
	}
	if (value == 4) {
		fadeamount = 1;
		fadespeed = 25;
	}
	if (value == 5) {
		fadeamount = 2;
		fadespeed = 25;
	}
	if (value == 6) {
		fadeamount = 2;
		fadespeed = 0;
	}
	if (value == 7) {
		fadeamount = 3;
		fadespeed = 0;
	}
	if (value == 8) {
		fadeamount = 4;
		fadespeed = 0;
	}
	if (value == 9) {
		fadeamount = 12;
		fadespeed = 0;
	}

}


/*
 * Function: SetDots
 * Used to read dot values and to draw the dots
 * Called when mode is "d"
 * Parameters: none
 */
void SetDots()
{
	dot1 = receivedChars[2] - '0';
	dot2 = receivedChars[4] - '0';
	DrawDots();
	pixels.show();
	type = old_type;
}

/*
 * Function: SetDotColors
 * Used to set both dot colors
 * Called when mode is "e"
 * Parameters: none
 */
void SetDotColors()
{
	int index = 2; int index2 = 0;
	while (receivedChars[index] != ';') {
		vals[0][index2] = receivedChars[index];
		index++;
		index2++;
	}
	index2 = 0; index++;
	while (receivedChars[index] != ';') {
		vals[1][index2] = receivedChars[index];
		index++;
		index2++;
	}
	index2 = 0; index++;
	while (receivedChars[index] != ';') {
		vals[2][index2] = receivedChars[index];
		index++;
		index2++;
	}
	index2 = 0; index++;
	while (receivedChars[index] != ';') {
		vals[3][index2] = receivedChars[index];
		index++;
		index2++;
	}
	index2 = 0; index++;
	while (receivedChars[index] != ';') {
		vals[4][index2] = receivedChars[index];
		index++;
		index2++;
	}
	index2 = 0; index++;
	while (receivedChars[index] != '\0') {
		vals[5][index2] = receivedChars[index];
		index++;
		index2++;
	}

	cdo[0] = atoi(vals[0]);
	cdo[1] = atoi(vals[1]);
	cdo[2] = atoi(vals[2]);
	cdo[3] = atoi(vals[3]);
	cdo[4] = atoi(vals[4]);
	cdo[5] = atoi(vals[5]);

	DrawDots();


	if (type == 'c') DrawTime();
	else if (type == 't') DrawTimer();
	pixels.show();
	type = old_type;
}

/*
 * Function: DrawDots
 * Used to draw the dots
 * Called when dots state or color gets changed
 * Parameters: none
 */
void DrawDots()
{
	if (dot1)pixels.setPixelColor(Digit3 - 1, pixels.Color(cdo[0], cdo[1], cdo[2]));
	else pixels.setPixelColor(Digit3 - 1, pixels.Color(0, 0, 0));
	if (dot2)pixels.setPixelColor(Digit3 - 2, pixels.Color(cdo[3], cdo[4], cdo[5]));
	else pixels.setPixelColor(Digit3 - 2, pixels.Color(0, 0, 0));
}

/*
 * Function: Set1DotColor
 * Used to set the color of a single dot
 * Called when mode is "h"
 * Parameters: none
 */
void Set1DotColor()
{
	int index = 4; int index2 = 0;
	char dotnr = receivedChars[2];
	while (receivedChars[index] != ';') {
		vals[0][index2] = receivedChars[index];
		index++;
		index2++;
	}
	index2 = 0; index++;
	while (receivedChars[index] != ';') {
		vals[1][index2] = receivedChars[index];
		index++;
		index2++;
	}
	index2 = 0; index++;
	while (receivedChars[index] != ';') {
		vals[2][index2] = receivedChars[index];
		index++;
		index2++;
	}
	index2 = 0; index++;
	while (receivedChars[index] != ';') {
		vals[3][index2] = receivedChars[index];
		index++;
		index2++;
	}
	index2 = 0; index++;
	while (receivedChars[index] != ';') {
		vals[4][index2] = receivedChars[index];
		index++;
		index2++;
	}
	index2 = 0; index++;
	while (receivedChars[index] != '\0') {
		vals[5][index2] = receivedChars[index];
		index++;
		index2++;
	}

	if (dotnr == '1')
	{
		cdo[0] = atoi(vals[0]);
		cdo[1] = atoi(vals[1]);
		cdo[2] = atoi(vals[2]);
	}
	if (dotnr == '2')
	{
		cdo[3] = atoi(vals[0]);
		cdo[4] = atoi(vals[1]);
		cdo[5] = atoi(vals[2]);
	}
	Serial.printf("Setting Dot Color of %c", dotnr);
	DrawDots();

	if (type == 'c') DrawTime();
	else if (type == 't') DrawTimer();

	type = old_type;
	pixels.show();
}

/*
 * Function: Set1DotColor
 * Used to set the color of a single dot
 * Called when mode is "h"
 * Parameters: none
 */
void Set1Color()
{
	int mydigit = receivedChars[2] - '0';
	int index = 4; int index2 = 0;
	while (receivedChars[index] != '\0' && receivedChars[index] != ';') {
		vals[0][index2] = receivedChars[index];
		index++;
		index2++;
	}
	vals[0][index2] = '\0';
	index2 = 0; index++;
	while (receivedChars[index] != '\0' && receivedChars[index] != ';') {
		vals[1][index2] = receivedChars[index];
		index++;
		index2++;
	}
	vals[1][index2] = '\0';
	index2 = 0; index++;
	while (receivedChars[index] != '\0' && receivedChars[index] != ';') {
		vals[2][index2] = receivedChars[index];
		index++;
		index2++;
	}
	vals[2][index2] = '\0';
	index2 = 0; index++;

	int t_r = atoi(vals[0]);
	int t_g = atoi(vals[1]);
	int t_b = atoi(vals[2]);
	Serial.printf("r:%d g:%d b:%d\n", t_r, t_g, t_b);

	if (mydigit == 1 || mydigit == 0) {
		cd[0] = t_r;
		cd[1] = t_g;
		cd[2] = t_b;
	};
	if (mydigit == 2 || mydigit == 0) {
		cd[3] = t_r;
		cd[4] = t_g;
		cd[5] = t_b;
	};
	if (mydigit == 3 || mydigit == 0) {
		cd[6] = t_r;
		cd[7] = t_g;
		cd[8] = t_b;
	};
	if (mydigit == 4 || mydigit == 0) {
		cd[9] = t_r;
		cd[10] = t_g;
		cd[11] = t_b;
	};
	type = old_type;
	if (type == 'c') DrawTime();
	else if (type == 't') DrawTimer();
	DrawDots();
	pixels.show();

}

/*
 * Function: SetColors
 * Used to set individual colors for all digits
 * Called when mode is "g"
 * Parameters: none
 */
void SetColors()
{
	int index = 2; int index2 = 0;
	while (receivedChars[index] != ';') {
		vals[0][index2] = receivedChars[index];
		index++;
		index2++;
	}
	vals[0][index2] = '\0';

	index2 = 0; index++;
	while (receivedChars[index] != ';') {
		vals[1][index2] = receivedChars[index];
		index++;
		index2++;
	}
	vals[1][index2] = '\0';
	index2 = 0; index++;
	while (receivedChars[index] != ';') {
		vals[2][index2] = receivedChars[index];
		index++;
		index2++;
	}
	vals[2][index2] = '\0';
	index2 = 0; index++;
	while (receivedChars[index] != ';') {
		vals[3][index2] = receivedChars[index];
		index++;
		index2++;
	}
	vals[3][index2] = '\0';
	index2 = 0; index++;
	while (receivedChars[index] != ';') {
		vals[4][index2] = receivedChars[index];
		index++;
		index2++;
	}
	vals[4][index2] = '\0';
	index2 = 0; index++;
	while (receivedChars[index] != ';') {
		vals[5][index2] = receivedChars[index];
		index++;
		index2++;
	}
	vals[5][index2] = '\0';
	index2 = 0; index++;
	while (receivedChars[index] != ';') {
		vals[6][index2] = receivedChars[index];
		index++;
		index2++;
	}
	vals[6][index2] = '\0';
	index2 = 0; index++;
	while (receivedChars[index] != ';') {
		vals[7][index2] = receivedChars[index];
		index++;
		index2++;
	}
	vals[7][index2] = '\0';
	index2 = 0; index++;
	while (receivedChars[index] != ';') {
		vals[8][index2] = receivedChars[index];
		index++;
		index2++;
	}
	vals[8][index2] = '\0';
	index2 = 0; index++;
	while (receivedChars[index] != ';') {
		vals[9][index2] = receivedChars[index];
		index++;
		index2++;
	}
	vals[9][index2] = '\0';
	index2 = 0; index++;
	while (receivedChars[index] != ';') {
		vals[10][index2] = receivedChars[index];
		index++;
		index2++;
	}
	vals[10][index2] = '\0';
	index2 = 0; index++;
	while (receivedChars[index] != '\0') {
		vals[11][index2] = receivedChars[index];
		index++;
		index2++;
	}
	vals[12][index2] = '\0';
	index2 = 0; index++;
	cd[0] = atoi(vals[0]);
	cd[1] = atoi(vals[1]);
	cd[2] = atoi(vals[2]);
	cd[3] = atoi(vals[3]);
	cd[4] = atoi(vals[4]);
	cd[5] = atoi(vals[5]);
	cd[6] = atoi(vals[6]);
	cd[7] = atoi(vals[7]);
	cd[8] = atoi(vals[8]);
	cd[9] = atoi(vals[9]);
	cd[10] = atoi(vals[10]);
	cd[11] = atoi(vals[11]);

	Serial.printf("Setting Colors: r:%s g:%s b:%s r:%s g:%s b:%s r:%s g:%s b:%s r:%s g:%s b:%s  \n", vals[0], vals[1], vals[2], vals[3], vals[4], vals[5], vals[6], vals[7], vals[8], vals[9], vals[10], vals[11]);
	type = old_type;
	if (type == 'c') DrawTime();
	else if (type == 't') DrawTimer();
	DrawDots();
	pixels.show();
}

/*
 * Function: SetBrightness
 * Used to set the brightness of the clock
 * Called when mode is "b"
 * Parameters: none
 */
void SetBrightness()
{
	int index = 2; int index2 = 0;
	while (receivedChars[index] != '\0') {
		vals[0][index2] = receivedChars[index];
		index++;
		index2++;
	}
	vals[0][index2] = '\0';
	int brightness = atoi(vals[0]);
	Serial.printf("Setting brightness to %d%%\n", brightness);
	pixels.setBrightness(brightness);


	type = old_type;
	if (mymode2 != '*')DrawDots();
	pixels.show();


	if (type == 'c' && mymode2 != '*') DrawTime();
	else if (type == 't' && mymode2 != '*') DrawTimer();
}

/*
 * Function: ModeClock
 * Updates time if the time difference to the last update exceeds 60 seconds
 * Called in the loop
 * Parameters: none
 */
void ModeClock()
{
	if ((millis() - timemillis) >= 60000)
	{
		long minidiff = millis() - timemillis;
		timemillis = millis() - minidiff;
		mins++;
		if (mins >= 60) {
			mins = 0;
			hours++;
		}
		if (hours >= 24) hours = 0;
		if (type == 'c')
		{
			if (mymode2 != '*')DrawTime();
			if (mymode2 != '*')DrawDots();
			pixels.show();
		}
	}
}

/*
 * Function: ModeClock
 * Updates the timer if the time difference to the last update exceeds 1 second
 * Called in the loop if mode is "t"
 * Parameters: none
 */
void ModeTimerDyn()
{
	if (T_hours <= 0 && T_mins <= 0 && T_secs <= 0)type = '1';
	else
	{
		if ((millis() - timermillis) >= 1000)
		{
			int minidiff = millis() - timermillis;
			timermillis = millis() - minidiff;
			T_secs--;
			if (T_secs <= 0)
			{
				if (T_mins > 0 || T_hours > 0)T_secs = 59;
				T_mins--;
				if (T_mins <= 0)
				{
					if (T_hours > 0)T_mins = 59;
					T_hours--;
				}
			}
			DrawTimer();
		}
	}
}


/*
 * Function: ModeWeather
 * If the weather display duration is reached, then the mode will be set to clock
 * Called in the loop if mode is "w"
 * Parameters: none
 */
void ModeWeather()
{
	if (mymode2 == '*')
	{
		DrawDigit(Digit1, ar, ag, ab, pt1);
		DrawDigit(Digit2, ar, ag, ab, pt2);
	}
	if (((millis() - weathermillis) / 1000) > weathersecs)
	{
		Serial.println("Setting mode back to Clock");
		type = 'c';
		if (mymode2 != '*')DrawTime();
		if (mymode2 != '*')DrawDots();
		pixels.show();
	}
}

/*
 * Function: TimerAlarm
 * Flashes all digits on/off and fades the colors
 * Called when the timer runs out (mode is = "1")
 * Parameters: none
 */
void TimerAlarm()
{
	if (alarmstate)
	{
		if ((millis() - timermillis) >= 350)
		{
			Serial.println("ALARM!");
			timermillis = millis();
			alarmstate = 0; pixels.setBrightness(0); pixels.show();
		}
	}
	else
	{
		if ((millis() - timermillis) >= 100)
		{
			Serial.println("ALARM!");
			timermillis = millis();
			alarmstate = 1; pixels.setBrightness(255);
			ShiftAlarmLeds(51);
			DrawDigit(Digit1, ar, ag, ab, 0);
			DrawDigit(Digit2, ar, ag, ab, 0);

			pixels.setPixelColor(Digit3 - 1, pixels.Color(ar, ag, ab));
			pixels.setPixelColor(Digit3 - 2, pixels.Color(ar, ag, ab));

			DrawDigit(Digit3, ar, ag, ab, 0);
			DrawDigit(Digit4, ar, ag, ab, 0);
			pixels.show();
		}
	}

}
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
void loop()
{
	if (!client.connected()) {
		reconnect();
	}
	client.loop();
	ModeClock();
	if (mqttdata > 0)serialNew();
	else if (type == 't')ModeTimerDyn();
	else if (type == 'w')ModeWeather();
	else if (type == '1')TimerAlarm();
	else if (type == '!')Alarm();
	if (mymode2 == '*')ModeFade();;
}
/* ----------------------------------------------LOOP END---------------------------------------------- */

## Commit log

2018-09-24 see changelog, switched to formatted output
2018-10-06 first upload
    [back_cover_40Infill_Black.stl, clock_mini v28.f3d, diffuser_100Infill_White_28x.stl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]
